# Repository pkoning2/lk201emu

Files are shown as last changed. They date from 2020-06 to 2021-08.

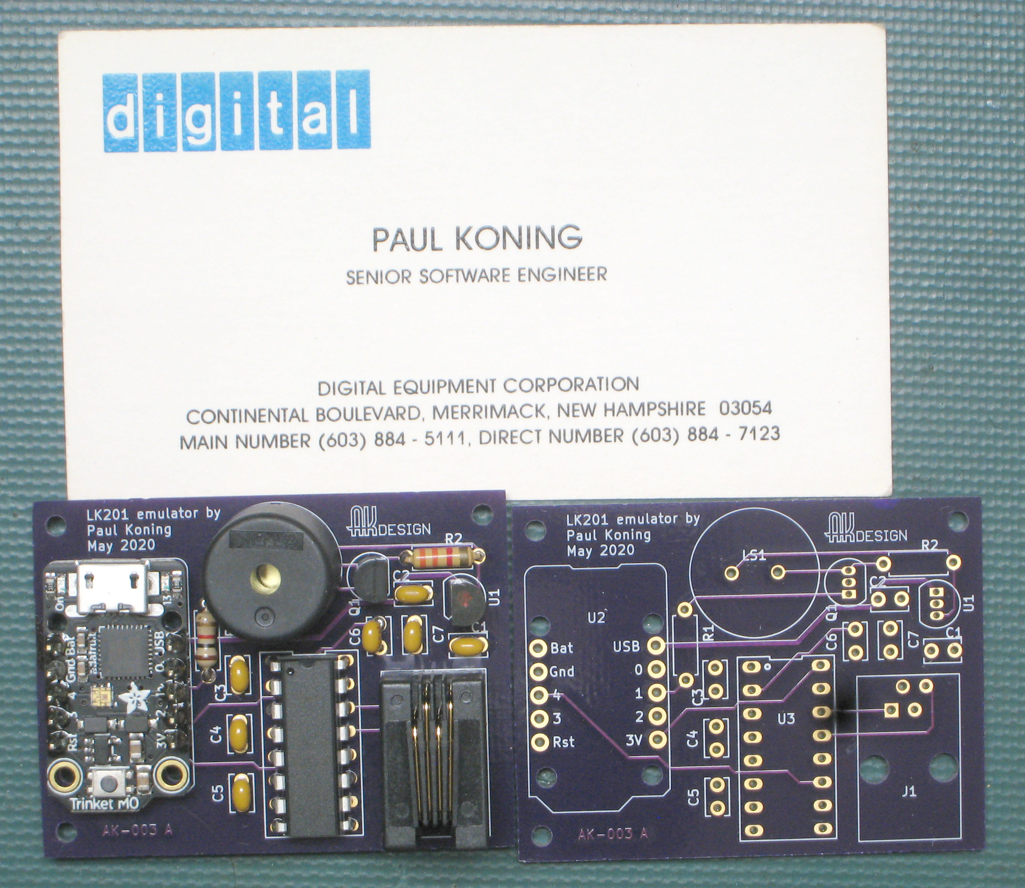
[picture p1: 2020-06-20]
doc/boards.jpg

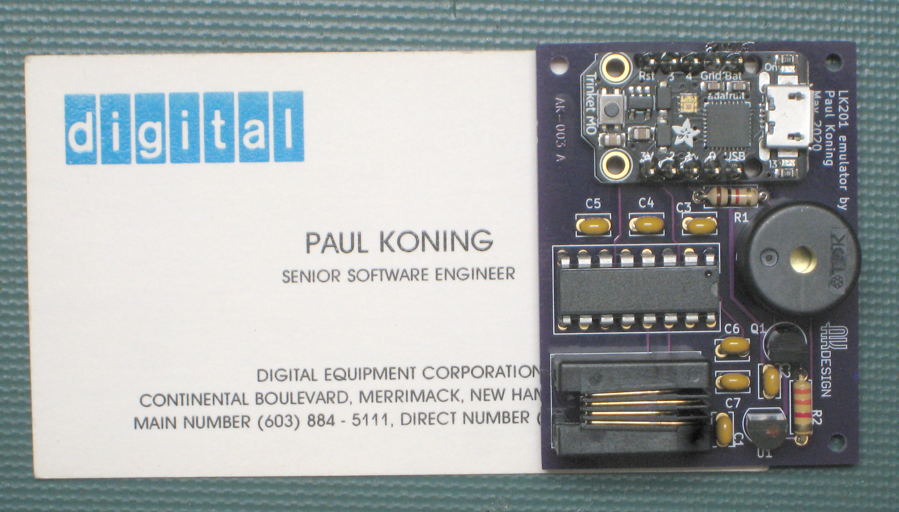
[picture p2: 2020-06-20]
doc/board.jpg

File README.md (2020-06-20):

# Digital Equipment LK201 keyboard emulator

This project allows a standard USB PC keyboard to be used as replacement for a DEC LK201 keyboard.  It consists of a small circuit built around an Adafruit Trinket M0 Arduino processor, and software for that to implement a USB host driver for the USB keyboard and the LK201 communication protocol. 

Subdirectory `lk201` is the Arduino software.  You can build it using the standard Arduino SDK, or use the prebuilt binary.

Subdirectory `kicad` is the circuit board design.  You can view it using the open source KiCAD package.

Subdirectory `doc` contains several documentation files in MD format.  File `emulator.md` describes the features of the emulator; `kicad` describes the board design and assembly information, and `software` describes the software and the load procedure.  There are also two JPG files that show the circuit board.

File `LICENSE` is the open source license under which this emulator is released.

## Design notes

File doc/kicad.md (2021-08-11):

# Digital Equipment LK201 keyboard emulators

The `kicad` subdirectory contains two subdirectories, `lk201` for the USB emulator and `lk201ps2` for the PS2 version.  In both you will find the design files for the emulator circuit board, which you can inspect or modify using the open source KiCAD package.

## Creating the circuit board

There are three ways to get a circuit board.
1. From the shared designs section of the OSHPark PCB fabricator website.  You will there both the [USB board](https://oshpark.com/shared_projects/zDjWDDDL "LK201 emulator") and the [PS2 board](https://oshpark.com/shared_projects/FJsOFwzi "LK201-PS2 emulator").
2. From any PCB fabricator that accepts KiCAD board files (such as OSHPark).
3. From any PCB fabricator that doesn't, by generating the standard *Gerber* files.

If you want to use a fabricator that needs Gerber files, open the `lk201.kicad_pcb` (USB) or `lk201ps2.kicad_pcb` (PS2) file using KiCAD (specifically the *Pcbnew* application) and use the File->Plot menu option to generate them.  You'll want to review the detailed instructions from the fabricator to confirm settings, file name rules, etc.

## Schematic

The board schematic is in `lk201.sch` (USB) or `lk201ps2.sch`.  You won't need this to create the board, but you can review this if you are interested, or if you want to modify the design.

## Assembly

The design is a simple circuit board with all through-hole components.  If you have experience building small electronic kits it should not create any problems.  If you do not, you may want to seek out some help since this is not a "Heathkit" style kit with detailed instructions or tutorials.

## USB board

### Parts list

Here are all the parts in the design, with schematic reference (also on the board silk screen labeling), value or device type, description, along with manufacturer name and Digikey part number.  The Digikey numbers are just by way of illustration.  Capacitors and resistors are generic, you can replace them by similar devices from other suppliers so long as they fit in the available space.  The capacitors  are small ceramic devices with 0.1 inch lead spacing; the resistors are standard 1/4 watt parts.  The transistor is a general purpose small NPN transistor, many other TO92 package transistors should work so long as the pinout matches.  Beware of the 2N2222, there are two variants with different pinouts!

If you don't want the key click and beep (bell) features, omit LS1, Q1, R1 and R2.
| Ref | Value | Description | Manufacturer | Digikey part # |
| --- | ----- | --- | --- | --- |
| C1 | 0.1uF | Unpolarized capacitor | Kemet | 399-14010-1-ND |
| C2 | 0.1uF | Unpolarized capacitor | Kemet | 399-14010-1-ND |
| C3 | 0.1uF | Unpolarized capacitor | Kemet | 399-14010-1-ND |
| C4 | 0.1uF | Unpolarized capacitor | Kemet | 399-14010-1-ND |
| C5 | 0.1uF | Unpolarized capacitor | Kemet | 399-14010-1-ND |
| C6 | 0.1uF | Unpolarized capacitor | Kemet | 399-14010-1-ND |
| C7 | 0.1uF | Unpolarized capacitor | Kemet | 399-14010-1-ND |
| J1 | RJ22 | RJ connector, 4P4C (4 positions 4 connected), RJ9/RJ10/RJ22 | Assmann WSW | AE10381-ND |
| LS1 | PS1420 | Crystal speaker/transducer | TDK Corporation | 445-2526-1-ND |
| Q1 | 2N3904 | 0.2A Ic, 40V Vce, Small Signal NPN Transistor, TO-92 | ON Semiconductor | 2N3904FS-ND |
| R1 | 1k | Resistor, 1/4 W | Stackpole | CF14JT1K00CT-ND |
| R2 | 3.3k | Resistor, 1/4 W | Stackpole | CF14JT3K30TR-ND |
| U1 | L78L05 | Positive 100mA 30V Linear Regulator, Fixed Output 5V, TO-92 | ST Microelectronics | 497-13127-1-ND |
| U2 | Trinket M0 | Adafruit Trinket M0 board (SAMD21) | Adafruit | 1528-2361-ND |
| U3 | ICL3232CPZ | Dual RS232 driver/receiver, 5V supply | Renesas | ICL3232CPZ-ND |

If you want to use Digikey as your supplier, the saved BOM is available [there](https://www.digikey.com/short/zrhrcz "Digikey BOM").

If you need alternate sources for various components, that should be no problem so long as the pinouts match.  For example, the MAX3232EPE transceiver has been reported as a valid alternative for U3.

### Assembly suggestions

I found that this order of installing the components works well:
1. U3 (16 pin DIP)
2. Resistors and capacitors
3. U1 (voltage regular) and Q1 (transistor)
4. LS1 (piezo beeper)
5. U2 (Trinket M0).  The board comes with a set of pins.  Cut off two 5-pin sections and solder these to the board, then slip the Trinket onto the pins and solder it.
6. J1 (RJ connector)

Note the correct orientation of U1, U2, U3, and Q1.

## PS2 board

### Parts list

Here are all the parts in the design, with schematic reference (also on the board silk screen labeling), value or device type, description, along with manufacturer name and Digikey part number.  The Digikey numbers are just by way of illustration.  Capacitors and resistor are generic, you can replace them by similar devices from other suppliers so long as they fit in the available space.  The capacitors  are small ceramic devices with 0.1 inch lead spacing; the resistors are standard 1/4 watt parts.  

If you don't want the key click and beep (bell) features, omit LS1 and R1.
| Ref | Value | Description | Manufacturer | Digikey part # |
| --- | ----- | --- | --- | --- |
| C1 | 0.1uF | Unpolarized capacitor | Kemet | 399-14010-1-ND |
| C2 | 0.01uF | Unpolarized capacitor | Kemet | 399-4150-1-ND |
| C3 | 0.1uF | Unpolarized capacitor | Kemet | 399-14010-1-ND |
| C4 | 0.1uF | Unpolarized capacitor | Kemet | 399-14010-1-ND |
| C5 | 0.1uF | Unpolarized capacitor | Kemet | 399-14010-1-ND |
| C6 | 0.1uF | Unpolarized capacitor | Kemet | 399-14010-1-ND |
| J1 | RJ22 | RJ connector, 4P4C (4 positions 4 connected), RJ9/RJ10/RJ22 | Assmann WSW | AE10381-ND |
| J2 | Mini-DIN-6 | 6-pin Mini-DIN connector | Adam Tech | 2057-MDJ-006-FS-ND |
| LS1 | PS1420 | Crystal speaker/transducer | TDK Corporation | 445-2526-1-ND |
| R1 | 3.3k | Resistor, 1/4 W | Stackpole | CF14JT3K30TR-ND |
| U1 | L78L05 | Positive 100mA 30V Linear Regulator, Fixed Output 5V, TO-92 | ST Microelectronics | 497-13127-1-ND |
| U1 | Itsy Bitsy (5V) | Adafruit Itsy Bitsy board, 5V version | Adafruit | 1528-2501-ND |
| U2 | ICL3232CPZ | Dual RS232 driver/receiver, 5V supply | Renesas | ICL3232CPZ-ND |

Warning: there are two versions of the Itsy Bitsy, as there are with many of the AVR based Arduino microcontrollers.  One has 3.3 volt I/O, the other has 5 volt I/O.  The PS2 design requires the 5 volt version.  Do not use the 3.3 volt version, it will be destroyed when you plug in the DEC side serial cable since that supplies 12 volts to the board and the 3.3 volt Arduino has a regulator that can only handle 6 volt max power input.  And even if the regulator could handle it, driving a PS2 keyboard with 3.3 volt logic levels will not work.

If you want to use Digikey as your supplier, the saved BOM is available [there](https://www.digikey.com/short/qbc941dj "Digikey PS2 BOM").

### Assembly suggestions

I found that this order of installing the components works well:
1. U2 (16 pin DIP)
2. Resistor and capacitors
4. LS1 (piezo beeper)
5. U1 (Arduino).  The board comes with a set of pins.  Cut off two 14-pin sections and a 5-pin section and solder these to the board, then slip the Itsy Bitsy onto the pins and solder it.
6. J1 (RJ) and J2 (mini-DIN) connectors.

Note the correct orientation of U1 and U2.

## Software load

After the board is built you will need to load the software.  See the software.md file for instructions.

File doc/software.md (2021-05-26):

# Digital Equipment LK201 keyboard emulators

The `lk201` subdirectory contains the software for the USB emulator circuit board, and the `lk201ps2` subdirectory contains the software for the PS2 emulator board.  These are two separate files, although the LK201 command parsing and serial link I/O code are the same in both files.  PC keyboard scan and decode are of course entirely different.  The audio output (beep and key click) are also different because of different hardware capabilities of the two Arduino devices used.

## Loading the software

### USB emulator board

An Arduino board such as the Adafruit Trinket M0 used in this project comes from the factory with a boot loader which is used to load the main program.  By default, the Trinket will connect as a device to the USB port of your computer.  But this emulator runs that same USB port in host (not device) mode, so after the initial programming it no longer talks directly to your PC or Mac by default.  The procedure given here also works fine for the initial load.

The solution is in the boot loader built into the Trinket:
1. Unplug the RJ22 serial cable (the connection to the DEC system).
2. Connect the Trinket to your computer.  If this is not the first time programming it, the Trinket will get power but will not make a connection because both sides are in USB host mode.
3. *Double click* the reset button.  The timing is slightly tricky; if done properly the small red LED next to the USB connector will blink (by slowly increasing and decreasing its intensity).  At this point, a `TRINKETBOOT` device will appear (USB attached FAT file system).
4. To use the prebuilt binary `lk201.uf2`, copy (drag and drop) that into the TRINKETBOOT device.  
5. Alternatively, use the Arduino SDK to compile and load the program source.

Either programming operation (3 or 4) will write the binary into the flash, then reset the Trinket (starting the software).  As a result the TRINKETBOOT device will suddenly disappear, which will probably result in a warning message from your computer's operating system about improper removal of the device. This is normal, the message can be ignored.

### PS2 emulator board

The PS2 emulator board is loaded through its micro-USB connector using the Arduino SDK.  

Unplug the RJ22 serial cable (the connection to the DEC system), then plug in a USB cable to your SDK machine.  Double click the reset button to enter the boot loader (the red LED on the Arduino board will blink), then use the SDK download operation.

## Dependencies

### USB emulator board

The `lk201.ino` source file is largely self contained.  To build it you will need the device libraries for the Adafruit Trinket M0 and the Adafruit ZeroTimer and DotStar libraries, all of which the SDK can download for you through the Library Manager.  You will also need the USB host library for SAMD based Arduino devices, available [on Github](https://github.com/gdsports/USB_Host_Library_SAMD "SAMD USB host library").

If you want to rebuild the `lk201.uf2` file, you will need the uf2conv.py utility available [on Github](https://github.com/microsoft.com "UF2 file format specification") in `utils/uf2conv.py`.  Proceed as follows:
1. Compile the program.
2. Use the `Export compiled binary` menu option to generate the `.bin` file.
3. Use `uv2conv.py` to convert that to a `.uf2` file.

### PS2 emulator board

The `lks201ps2.ino` source file is self-contained.  To build it you just need the device libraries for the Adafruit Trinket (classic AVR chip, not M0).

## Options

There is only one build option: change `#define DOIDENT 1` to `#define DOIDENT 0` to eliminate the identification message at device powerup.

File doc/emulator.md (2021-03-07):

# Digital Equipment LK201 keyboard emulators

The emulator allows a standard PC-style keyboard to be used as a replacement for a DEC LK201 keyboard.  This is useful if you don't have an LK201 keyboard, or if all the ones you have stopped working, as happened to me.

There are now two emulators: one for USB keyboards, and a different one for PS-2 (round connector) keyboards.  The circuit for the two is rather different, but the software functionality is the same for both.

The USB emulator circuit has two connectors: a modular jack which accepts the LK201 keyboard cable, and a USB connector.  The USB connector on the Trinket board is a micro-B connector; your keyboard presumably needs an A jack.  There are various ways to convert from one to the other; [Adafruit](https://www.adafruit.com/product/1099 "Micro B to A cable") sells one.

The PS2 emulator circuit has a modular jack for the LK201 keyboard cable and a standard PS2 mini-DIN connector for the keyboard.  If you have a very old PC keyboard with a standard size DIN connector (5 pins), you'll need an adapter for that; the board design I created does not accommodate a standard size connector.  Note that those old keyboards may have fewer keys, in which case you may want to adjust the key mapping in the software.  Also, some of them draw too much current for the regulator on the Arduino board.  If so, you will need to modify the circuit to add an external 12 to 5 volt regulator to feed the PS2 keyboard jack, rather than relying on the 5 volt out from the Arduino board.

## Keyboard mapping

For the most part, the keys on the PC keyboard correspond directly to the same keys on the LK201.  This applies to all the letters and digits as well as most punctuation.  Similarly, F1 through F12 are the same in both, as are the cursor keys and most of the numeric keypad keys.  Both shift keys are shift, but only the left control key is control.

Some other keys are different on the two keyboards.  Sometimes similar key labels exist but the positions are different; in that case I have chosen to map the keys by their positions.

| PC keyboard key | LK201 key |
| --- | --- |
| Left Windows | < > |
| Left Alt | Compose |
| Esc  | F11 |
| Insert | Find |
| Home | Insert Here |
| PgUp | Remove |
| Delete | Select |
| End | Prev Screen |
| PgDn | Next Screen  |
| PrtScr | F14 |
| Scroll Lock | Help (F15) |
| Pause | Do (F16) |
| Right Alt | F17 | 
| Right Windows | F18 |
| App Menu | F19 |
| Right Control | F20 |
| Num Lock | PF1 | 
| Num keypad / | PF2 |
| Num keypad * | PF3 |
| Num keypad + | Num keypad , |

Note that the PF4 and F13 keys are not available, I ran out of places to put them.

Also, on PS2 keyboards due to an oddity in the way the key is handled, the Pause key (used for the LK201 "Do" function) does not support LK201 up/down modes and will not auto-repeat.  The keyboard always pretends that this key is immediately released, so it is not possible to simulate the normal operation.

## Lights

Standard PC keyboards have only three LEDs, while the LK201 has four.  The mappings are:

| PC keyboard LED | LK201 keyboard LED |
| --- | --- |
| Scroll lock | Hold screen |
| Caps lock | Lock |
| Num lock | Compose |

The WAIT light is not on the keyboard but is provided by the LED on the center of the Arduino board.  On the USB version, that is a multi-color LED, set to green for the WAIT indicator.  On the PS2 board, this LED is red.

## Trinket middle LED color coding (USB keyboard emulator)

When operating, the emulator uses the middle LED for the LK201 WAIT light, in green.  Other colors are used during initialization, to reflect the phases of the USB discovery.
* Purple: settling.
* Blue: waiting for device.  This is the code you will see when no keyboard is plugged in.
* Yellow: attached, reset device.
* Orange: wait for device reset complete.
* Cyan (light blue): configuring device.  If the board stays in this state, the USB device is not compatible with this software.

When the USB initialization completes, there is a brief bright green flash.

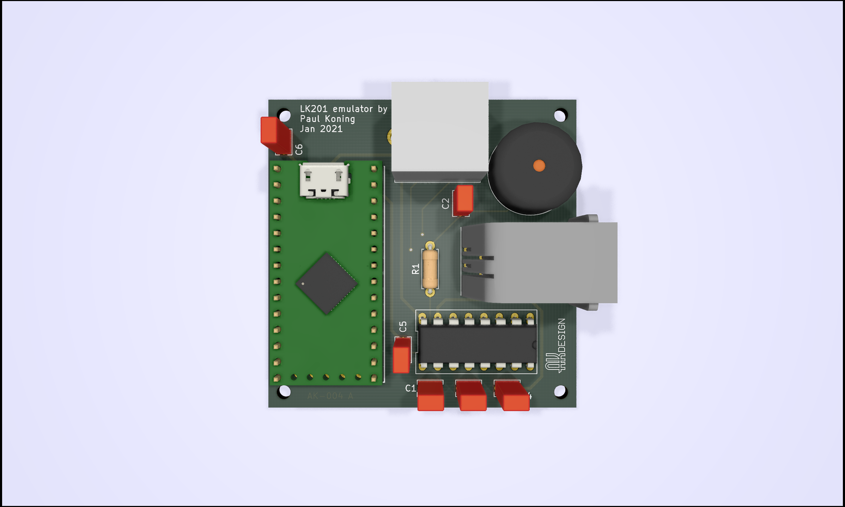
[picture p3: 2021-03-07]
kicad/lk201ps2/lk201ps2.png

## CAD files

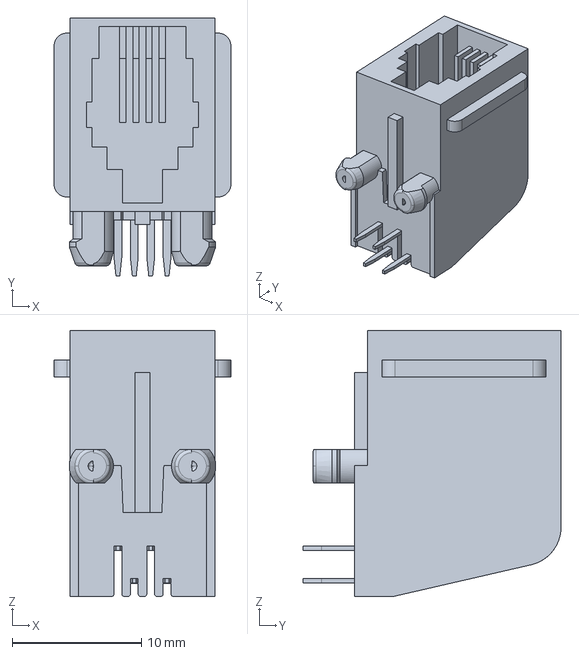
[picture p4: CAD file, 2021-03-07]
kicad/lk201_parts/modular_jack_a-20040.step
13.7 x 20.0 x 20.6 mm

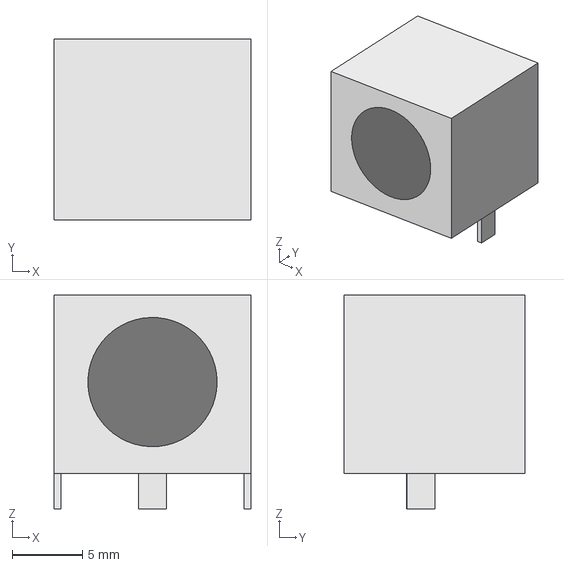
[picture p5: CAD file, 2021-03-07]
kicad/lk201_parts/MDJ-00x.step
14.0 x 12.9 x 15.2 mm

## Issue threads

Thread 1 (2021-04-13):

Some questions

toncho11, 2021-04-13:
Hi,

Great project! I have one vt220 without a keyboard and I would like to make one.

But you use a USB converter from the keyboard's USB type A to the MicroUSB of the Adafruit Trinket M0, right?

Do you have cards for sale?

pkoning2, 2021-04-14:
Thanks Toncho!

I assume by "converter" you mean some sort of active device.  No, it doesn't need that.  All that is needed is a cable that goes between the two connector types.  Adafruit has one, it is mentioned in the documentation (emulator.md), https://www.adafruit.com/product/1099 .
I don't have cards for sale.  My intent was to provide the design, both software and hardware.  You can buy the board (bare board) from OSH Park at the link given in kicad.md, or you can use the kicad design files to create a board file for some other fab shop if you prefer.  The parts are available from many suppliers; I included a BOM link at Digikey, but you can use others if you prefer.  The assembly instructions are included in the documentation as well.  It's a pretty simple item, just barely harder than "Heathkit".  In particular, no surface-mount parts.  A simple hobbyist-grade small soldering iron and some electronic-grade rosin-core solder is really all you need.

toncho11, 2021-04-30:
Hi again,

I got my card and I soldered the capacitors and resistors already. One thing is that there is not much space between the legs for the capacitors and especially for the transistor and the voltage regulator. One needs a very good soldering station with a thin head. I soldered two legs together at some point.

Question: is it possible to re-program the Adafruit Trinket while soldered? With the Arduino this is not the case because it does not accept a new program if the RX pin is connected to something. I will need to do adjustments in the code as my terminal is not a regular one. It has a modified ROM for my native language. So can you apply changes while it is already soldered? Maybe I should use a socket?

Thanks again for the project. I am advancing.

pkoning2, 2021-04-30:
Yes, the Trinket can be reprogrammed while soldered.  See the instructions in doc/software.md, section "Loading software".  This works because on the Trinket the programming operation does not use the UART, instead it uses the USB.

You mention that you have a "modified ROM".  Do you mean you have a terminal that uses a non-English LK201, for example the French (AZERTY) layout?  That does not make any difference.  The LK201 keycodes are for the key locations, so the keycode that is Q on the English model is used for A on the French one.  The handling of the different keyboard layouts is in the terminal microcode, not in the keyboard.  That does mean, of course, that you need a USB keyboard with the French layout if you have a terminal that wants a French LK201.  If you want to use an English layout USB keyboard for use with a French terminal, then yes, you'd have to change the translation table in my program so that -- for example -- the USB keystroke for the letter A is sent as the LK201 keycode for Q.

I have the Renesas RS232 part, which I get from Digikey -- a USA based distributor that has good prices, as does Mouser (also in the USA).  I don't know about similar companies in Europe, but I would expect they exist.  I would guess the CP would be comparable.  The main question is whether the pin assignment matches.  I would expect it does, normally the pins are standard and later versions of the same circuit use the same definitions.

toncho11, 2021-04-30:
No, it is not French, but Bulgarian. Actually I am not sure what to expect as I have not seen it in operation. It displays things in English, but with Cyrillic alphabet ...

Digikey ... can cost a lot for delivery (usually 20 euros) and then you might have import taxes of unknown value that you pay at delivery ... One guy says that for 52 euros of purchase he got 32 euros of additional taxes from UPS ...

pkoning2, 2021-04-30:
Toncho, I did not mean to suggest using Digikey if you're outside north America.  I understand the problem of shipping and taxes.  My idea was that I would expect companies similar to Digikey (electronic parts distributors) to exist in other parts of the world.  If there is one in the EU that would be a much better option for you.  Ebay is fine too, if the parts you get that way are real.
On the keyboard: if the terminal expects an LK201, the emulator should work.  A given key on your USB keyboard would have display the same way on that terminal as the corresponding key location does on a real LK201 keyboard.  If you don't know exactly what the layout should look like, the best answer is to use the existing software to start, and then test with that to see if any changes are needed.  The conversion from USB codes to LK201 codes comes from the usb_lk201 table in lk201.ino, you can change that to be any mapping you want, then rebuild and reload using the instructions in doc/software.md.

toncho11, 2021-04-30:
Here is a comparison with:

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

There is only 1 driver in the no Z version. Would this be a problem? Also size is a bit different.

pkoning2, 2021-04-30:
That is very strange.  I've searched for the ICL3232CP and as far as I can tell it is simply the same as the CPZ except that the CPZ is lead-free.  Certainly that's what the Renesas data sheets I have found tell me.
I can't see the information you posted.  Can you look at the data sheet referenced in the CP column and post it here?  I can look at it.  But it sounds like what you have there is not a real ICL3232CP.  I also don't know what it means to have an RS232 "transceiver".  It may be compatible, or not.
Your best solution is to search for another supplier who can sell you an actual ICL232CPZ.  Or any other 16-bit 2rx 2tx RS232 chip that has the same pinout.  It's a standard design, I'm sure there are other suppliers.  Just make sure that it handles 3.3 volt supply, 3.3 volt I/O, and has the correct pinout.

pkoning2, 2021-04-30:
Interesting.  I think Mouser is simply wrong, and the explanation is what I said: the CP is simply the older non-RoHS version of the CPZ.  So use either one.

toncho11, 2021-05-03:
MAX3232ECPE looks pin compatible. It is also 2rx 2tx. I can buy it from ebay/aliexpress without an expensive delivery.

pkoning2, 2021-05-03:
No, it's not.  That is an 18 pin device, not 16 pin.  You could certainly modify the design to use it, but the existing schematic and board won't work for that.

toncho11, 2021-05-03:
I do not see a pdip version with 18 pins in the specification. It says pdip 16?

https://eu.mouser.com/datasheet/2/256/MAX3222E-MAX3246E-349176.pdf

pkoning2, 2021-05-03:
You're right, my mistake.  I looked in the wrong spot.  I agree with you, that is a compatible part, it should work.

toncho11, 2021-05-20:
Hi,

For the PS1420 I already have a piezo beeper from another project:

Tension: 3,5 à 5,0 volts.
- Consommation: <25 ma.
- Fréquence: 2300 hz (+/- 500 hz).
- Puissance sonore: 85 dB minimum à 10cm.

It has + and - though. How should I put it?

pkoning2, 2021-05-20:
You're talking about the USB version, right?  Pin 1, on the left (near the Arduino board) is the + terminal.

toncho11, 2021-05-20:
Yes. USB. Thanks. It can be added on the board for the future versions :).

pkoning2, 2021-05-20:
You mean add a + symbol?  Good idea, will do.

toncho11, 2021-05-21:
Yes for the "+".

How did you solder the pins of the Adafruit chip? From both sides of your card?
These pins have a plastic part, did you remove it?

I ordered the last parts I need to complete your card. :)

pkoning2, 2021-05-21:
I soldered the pins only from the back of the board and the top of the Trinket.  Left the plastic in place.  I never solder things from both sides, because the solder reaches both sides anyway thanks to the plated through holes.

toncho11, 2021-07-15:
![Uploading IMG_20210715_202506.jpg…]()

This is the final product.

toncho11, 2021-07-15:
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

pkoning2, 2021-07-15:
Looks good!

Closed 2021-07-15.

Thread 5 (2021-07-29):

On using the adapter

toncho11, 2021-07-29:
Hi,

I managed to finally plug the adapter. In general it is working.

1) So the F3 key (on the USB keyboard) switches between menu and writing modes? Right?
2) Can you type (do letters show) on the VT220 terminal without attaching it to a computer through serial?

I use the right "ENTER" for selecting options in the menu.

pkoning2, 2021-07-29:
Yes, F3 is the "Setup" function key on VT2xx and later terminals.  (Not on the Pro, though, it has a different function key layout.)
I don't have a VT220, so I have to look in a manual to remind myself what it does.  The way I normally navigate the menu is using the cursor  keys, then Enter to do the selected action.
One of the options on the first setup screen is "On-line" which if you select and Enter should change to "Local".  That makes keyboard data go to the display directly, without any communication to any host.
The red light on the Arduino is the "Wait" LED (the fourth LED on the LK201).  I did it that way because I want all four to be visible, the other three are handled using the three PS keyboard LEDs.  See the documentation, it's mentioned in there.

toncho11, 2021-08-01:
Thanks!!!

The terminal though is only in cyrillic letters using English words in whatever language you choose. I guess they adapted the ROM, so that one can type in cyrillic, but in the end I do not see how to switch to English. It is because cyrillic was not built in, so they had to make un eagly hack. I think the only solution is an original ROM.

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

pkoning2, 2021-08-01:
Yes, looks like they replaced lower case letters by Cyrillic capital letters.  The original ROM would be the best solution.  Or use only upper case...

toncho11, 2021-08-01:
Nice observation! It does work with capital letters in English.
I still need both if I want to connect to a Linux terminal.
Some strategy can be developed!

I can add a code after your code in the adafruit controller:
- each capital letter is converted to lower initially
- when F6 (for example) is pressed then it goes upper case

toncho11, 2021-08-02:
Actually I need another micro controller on the serial port output in order to do that, The display will always stay in English capital letters even if I manage to send both lower and capital letters to the connected computer,

toncho11, 2021-08-11:
You can update that:

Max3232EPE driver/receiver is also compatible as U3.

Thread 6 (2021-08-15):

Keyboard blinking constantly, very intermittent keypresses going through

abzman, 2021-08-15:
OK, this has been bugging me for a while and I think I've finally fixed it but I want to know how this ever worked for anyone else.  The lines 938-940 in lk201.ino seem to mean that every time the keyboard is connected, the software disconnects it.  I commented out those three lines and now it works perfectly.  What I want to know is why were those lines in there at all? did it work as is for anyone else? should I issue a pull request that deletes those three lines?

abzman, 2021-08-15:
I take it back, it doesn't work perfectly for me now, it boots up and the usb state goes to green, then off just before it throws a keyboard error, but after that any character I type makes it green again and seems to work perfectly

pkoning2, 2021-08-18:
Unfortunately it's hard to do good error handling given that there is no real way to send error reports.  At one point I had it send various distinct error codes as different morse code letters.
The purpose of line 938 is to send the standard LK201 power-up notification to the host or terminal.  That tells it there is a keyboard, and if the controlling device wants to set any non-standard keyboard settings it would generally do so in response to that notification.  For example, RSTS would change the edit keys to be autorepeat, not up/down as is the surprising default, and it would turn off keyclick so it can generate clicks in the driver to acknowledge those keys for which it wants the click.
Do you have the powerup beeping enabled (the little morse code sequence)?  If there's an error that crashes the controller it would resend that sequence.  If you're just seeing various light colors and blinking, that means the USB state machine is recycling through its state.  I could imagine that being a broken keyboard, or a bad USB cable.  If you can swap keyboards or cables or the cable adapter, that's worth a try.
It's been very reliable for me (though right now I'm using the PS2 version instead) and I've had one other report of successful operation (toncho11, who posted various comments here in weeks past).

abzman, 2021-08-18:
I've been working on other projects so I may not get to debugging this for a little while, I have two brand new keyboards to use with this but I have three others to try as well.  I know the keyboards work, but I'm not hearing any beeping.  My next test was to make sure my beeper circuit works.  I'll let you know how it goes, I may try to bodge on a software serial port for debug messages

pkoning2, 2021-11-05:
Any news?  Did you get it to work or are you still seeing problems?

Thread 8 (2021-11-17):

No reason the PS/2 emulator couldn't be implemented on an Arduino Pro Micro?

ej0rge, 2021-11-17:
Hey, i am excited about this project. I have a VT220 and a working LK201 (and VT1200 and LK401) but i loathe the key feel of these old membrane keyboards. I've got boards inbound from jlcpcb.

I've got no heartburn about ordering an Itsy Bitsy 5v from adafruit, but i have a thing for building things Small, no real fear of light duty hot air smt work, and half a dozen Arduino Pro Micro 5v clone boards in a drawer.

The Itsy Bitsy is cheaper than a Genuino Pro Micro, but 3x the cost of a chinese clone Pro Micro.

I sort of know my way around kicad and while I'm a terrible coder i can manage to make small changes without getting completely lost. It looks like at worst i might have to use different pins for the PS/2 interface if i compiled for the APM.

After looking through the schematic I am pretty sure i could lay out a board with an smt max232 equivalent and smt capacitors and resistor on a board no wider than the APM and fit a buzzer under there too, with the mini-din 6 on one end and rj22 (or just a JST-XH for a custom cable) on the other. And design a very small 3d printed enclosure, maybe with a cable clamp for telephone station cable with an RJ22 plug crimped on the end. I have a crimper and ends, pretty sure.

I would consider this a fun project.

Am i missing anything?

pkoning2, 2021-11-17:
Hi, thanks for the feedback.

The only real requirement is that you have an Arduino, and it should have 5V I/O, with enough pins to drive the signals used in the design.  I did my original debugging with a Metro prototyping board.  If you don't use an Itsy Bitsy then you probably need to adjust the board.   If the pinouts differ then that may need to change as well, and if that means different pin numbers the "pin assignment" defines at the top of the source file would need adjustment.

If necessary you can leave out the buzzer, though of course that means no key click and no "bell".  If your board doesn't have a built-in LED, then either you can omit the WAIT LED, or wire up an LED to some available pin and change the WAITLED define to match.

The changes you proposed all sound fine.  I'd like to see your finished work, it sounds nice.

ej0rge, 2021-11-18:
Yes the pins of the two modules are substantially different, and the PS/2 port will have to be assigned to different pins when the firmware is built.

I think I'll keep the buzzer but might use a different part.  I haven't dug into the code but it looks like you are using a pwm pin to drive it through the unused output pin on the 232 driver. Clever. That same pin is still broken out on the arduino pro mini.

pkoning2, 2021-11-18:
Yes, the idea of driving a buzzer through an RS-232 driver was lifted from another LK201 adapter design.  The PWM is to get the variable loudness.  And the RC filter actually makes that work; unfiltered the different width pulses sound different in character but not really in loudness.

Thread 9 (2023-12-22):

Thanks and suggestion for function keys > 12

snhirsch, 2023-12-22:
First of all, thanks for your efforts in developing these devices.  I built a USB converter and everything went quite well.

I do have a suggestion / wish-list item:  Why not map Shift + Fn to F(n+10)?  That's somewhat common in both the Windows and Linux ecosystems.  Rather than move to the bottom right for, e.g. F17 one could just do Shift+F7.  Is there a technical reason that would prevent this from working?

pkoning2, 2023-12-22:
That would be somewhat tricky.  Keep in mind that this is basically a scan code translator.  So when you press F7 it sends the keycode for that; when you press a shift key it sends the keycode for shift.  The converter doesn't care about the shift state when it generates the keycodes; the host driver is responsible for that aspect.
While it may be that shifted function keys have no standard meaning in typical DEC products, there certainly isn't anything that prevents that from being done, at least not in systems where that processing is in software (like the DEC Pro).

snhirsch, 2023-12-22:
Ah - ok.  I definitely see your point.  Didn't realize the converter held no state!  But as you say that is definitely the safest and most compatible approach.

pkoning2, 2023-12-23:
It does have some state, because it has to send "all up" when the last of the up/down keys is released, rather than the keycode for that key.  But other than that the coding of the keys does not depend on shift or other modifier state.

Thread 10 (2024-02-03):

Help needed

Kisko93005, 2024-02-03:
Hello,
Recently, I've took out an old Rainbow 100 computer with an VR201 and lk201 keyboard from my basement. After trying to boot it up i was given an keyboard error 13. After I disconnected membrane ribbons from keyboard's electronics the computer booted normally, which most likely means shorted membrane, which is apparently impossible to repair.

Trying to find solution to my problem i have found this project. Because Adafruit Trinket M0 is almost imposible to get in my country without paying huge shipping costs for an international courier delivery I tried to make PS/2 version of your project. I don't have an Itsy Bitsy but i have a arduino micro which uses the same exact processor. After wiring it to PS/2 keyboard and the Rainbow through ADM232 chip(I connected everything according to the schematic except i changed PS/2 keyboard pins (physically and in the code) from 11 and 12 to 5 and 6 because there's no pin 11 on my arduino micro) I powered it up but it gives me keyboard error 13. I don't know what to do anymore.

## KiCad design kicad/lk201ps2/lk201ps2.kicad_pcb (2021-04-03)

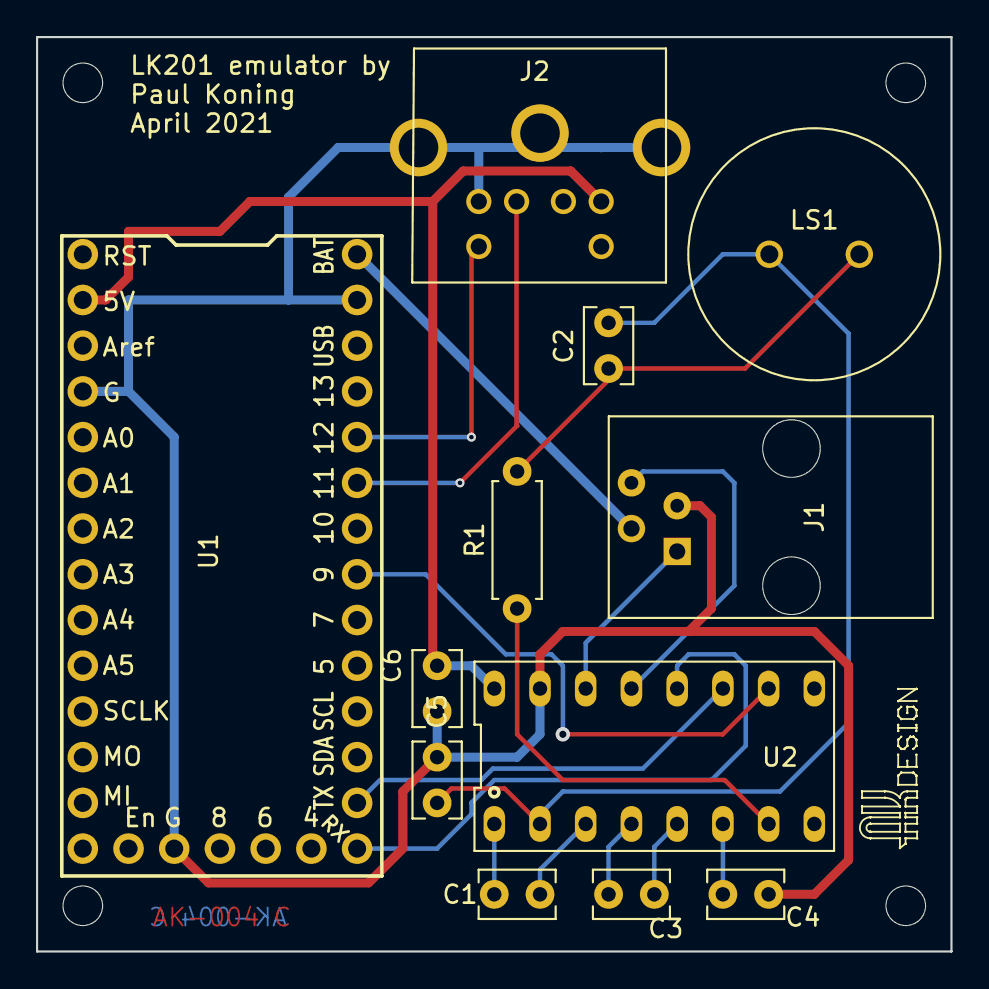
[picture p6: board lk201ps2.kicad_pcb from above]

Board: 2 copper layers, 50.8 x 50.8 mm, 12 parts (0 on the bottom side), 18 nets.

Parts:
C1, C3, C4, C5, C6: 0.1uF; C_Rect_L4.0mm_W2.5mm_P2.54mm
C2: 0.01uF; C_Rect_L4.0mm_W2.5mm_P2.54mm
J1: RJ22
J2: Mini-DIN-6; MDJ-006
LS1: PS1420; PS1420_buzzer
R1: 3.3k; R_Axial_DIN0207_L6.3mm_D2.5mm_P7.62mm_Horizontal
U1: Itsy_Bitsy_5V; Itsy
U2: ICL3232CPZ; DIP-16_296_ELL

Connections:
/V5: C6.1, J2.4, U1.2, U2.16
/V12: J1.2, U1.33
/VS+: C2.2, C5.2, LS1.2, U2.2
GND: C4.1, C5.1, C6.2, J1.3, J2.3, J2.SH, U1.4, U1.16, U1.32, U2.15
unnamed: C1.1, U2.1
unnamed: C1.2, U2.3
unnamed: C2.1, LS1.1, R1.2
unnamed: C3.1, U2.4
unnamed: C3.2, U2.5
unnamed: C4.2, U2.6
unnamed: J1.1, U2.14
unnamed: J1.4, U2.13
unnamed: J2.1, U1.28
unnamed: J2.5, U1.29
unnamed: R1.1, U2.7
unnamed: U1.20, U2.12
unnamed: U1.21, U2.11
unnamed: U1.26, U2.10

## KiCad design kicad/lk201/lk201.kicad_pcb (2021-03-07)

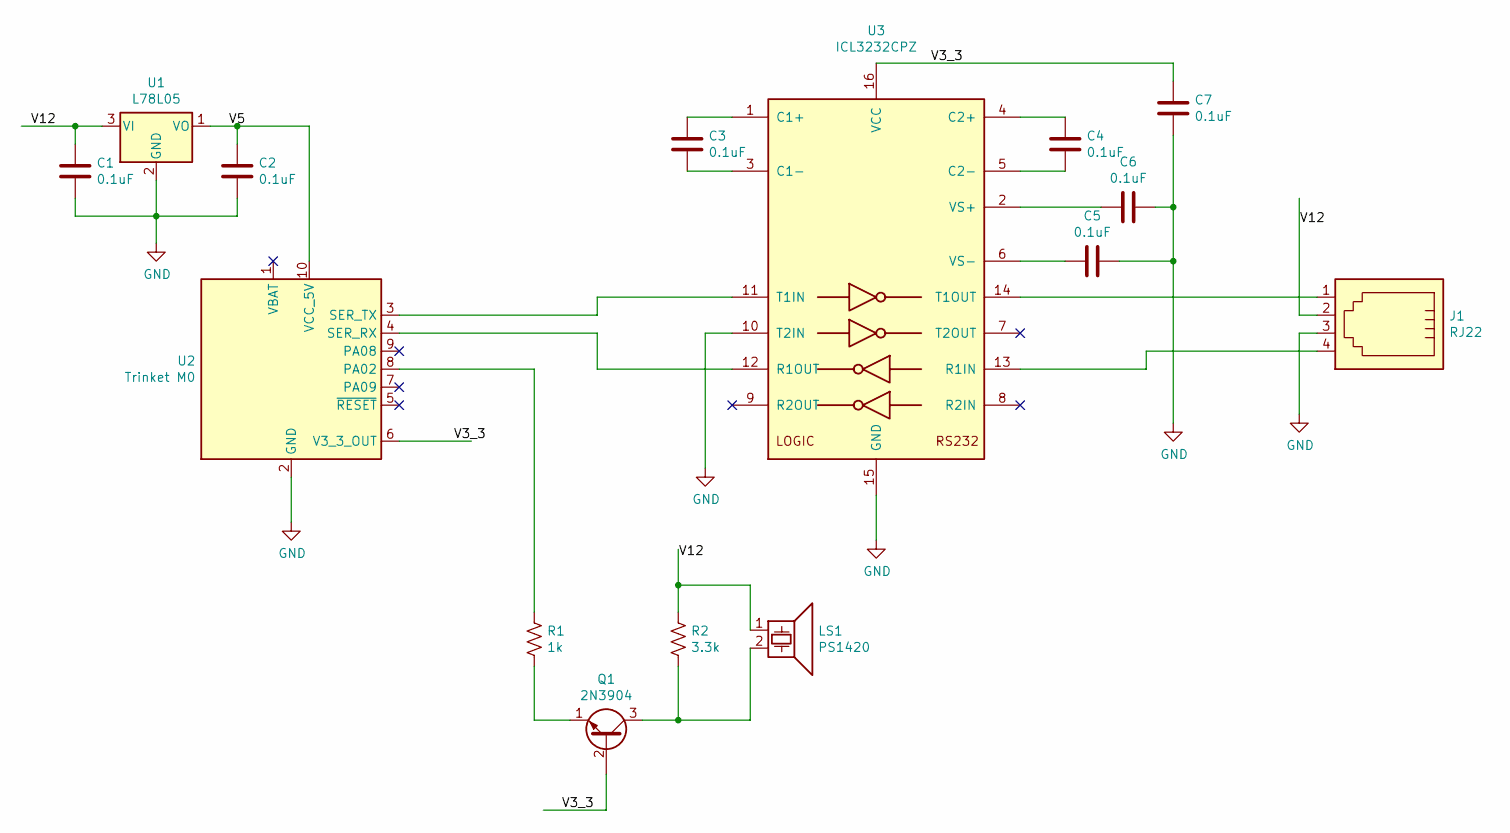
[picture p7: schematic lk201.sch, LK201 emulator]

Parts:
C1, C2, C3, C4, C5, C6, C7: 0.1uF; C_Rect_L4.0mm_W2.5mm_P2.54mm
J1: RJ22; Mfg part A-2004-3-4-LP-N-R; Digikey  AE10381-ND
LS1: PS1420; PS1420_buzzer
Q1: 2N3904; TO-92_Inline_Narrow_Oval
R1: 1k; R_Axial_DIN0207_L6.3mm_D2.5mm_P7.62mm_Horizontal; Mfg part CF14JT1K00; Digikey CF14JT1K00CT-ND
R2: 3.3k; R_Axial_DIN0207_L6.3mm_D2.5mm_P7.62mm_Horizontal; Mfg part CF14JT3K30; Digikey CF14JT3K30TR-ND
U1: L78L05; TO-92_Inline_Narrow_Oval
U2: Trinket M0; Trinket_M0; Mfg part 3500; Digikey 1528-2361-ND
U3: ICL3232CPZ; DIP-16_296_ELL; Mfg part ICL3232CPZ; Digikey ICL3232CPZ-ND 

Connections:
/V3_3: C7.1, Q1.2 (B), U2.6 (V3_3_OUT), U3.16 (VCC)
/V5: C2.1, U1.1 (VO), U2.10 (VCC_5V)
/V12: C1.1, J1.2, LS1.1, R2.1, U1.3 (VI)
GND: C1.2, C2.2, C5.1, C6.1, C7.2, J1.3, U1.2 (GND), U2.2 (GND), U3.10 (T2IN), U3.15 (GND)
unnamed: C3.1, U3.1 (C1+)
unnamed: C3.2, U3.3 (C1-)
unnamed: C4.1, U3.4 (C2+)
unnamed: C4.2, U3.5 (C2-)
unnamed: C5.2, U3.6 (VS-)
unnamed: C6.2, U3.2 (VS+)
unnamed: J1.1, U3.14 (T1OUT)
unnamed: J1.4, U3.13 (R1IN)
unnamed: LS1.2, Q1.3 (C), R2.2
unnamed: Q1.1 (E), R1.2
unnamed: R1.1, U2.8 (PA02)
unnamed: U2.3 (SER_TX), U3.11 (T1IN)
unnamed: U2.4 (SER_RX), U3.12 (R1OUT)

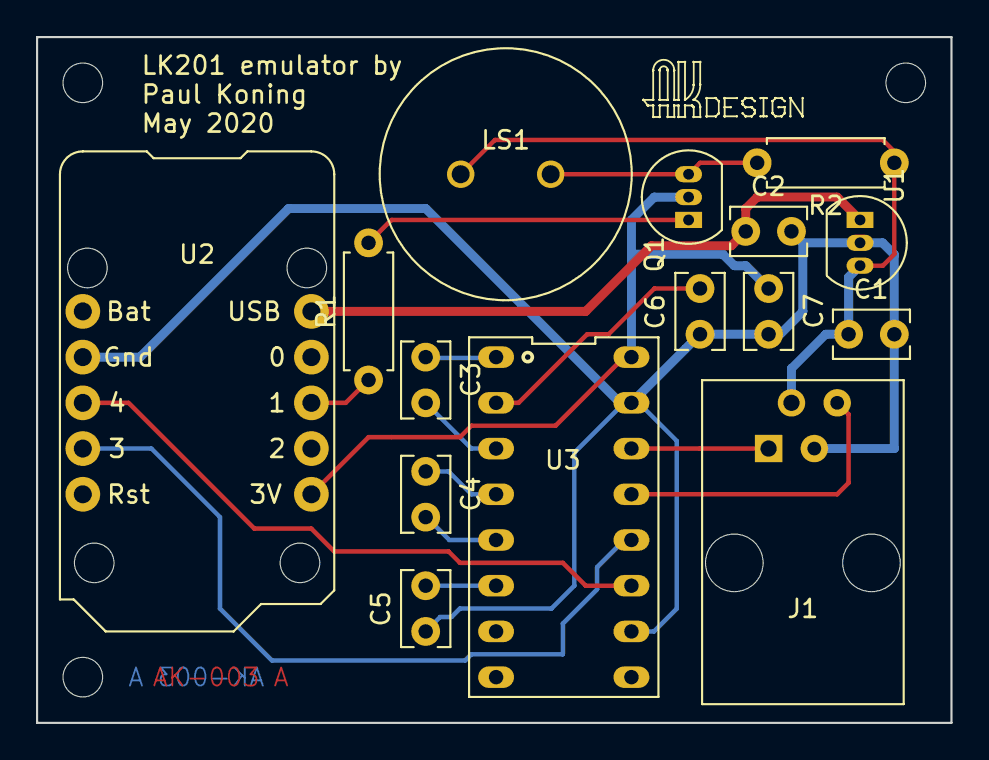
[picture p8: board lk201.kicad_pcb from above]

Board: 2 copper layers, 50.8 x 38.1 mm, 15 parts (0 on the bottom side), 17 nets.

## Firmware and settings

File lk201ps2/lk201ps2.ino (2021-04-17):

/*
 LK-201 emulator

 Interfaces between a DEC terminal or workstation that expects an
 LK201-AA keyboard and a standard PS2 connector PC keyboard.

 Copyright (c) 2020-2021, Paul Koning

 Please read file LICENSE for the license that applies to this project.
*/

#define DOIDENT 1   // Set to 0 to suppress power up ident

/*
 Parts of this code were taken from various sample files:

 Polled PS-2 keyboard controller copyright 2009 by Bill Westfield.
 */

#include <Arduino.h>

#include "wiring_private.h"
#include "pins_arduino.h"

// Pin assignment

#define APIN 9              // PWM output, 2 kHz.
#define PS2CLK 12
#define PS2DAT 11
#define WAITLED LED_BUILTIN // pin for Wait LED


// PC 105-key keyboard to LK201 mapping.
//
// Entries in the main lookup table are keyed by the scan code.  The
// value is the LK201 keycode.  Entries in the "divs" table are keyed
// by LK201 keycode, and give the "keyboard division" number which
// selects the mode (up/down, autorepeat, down only) and, if
// applicable, autorepeat parameter buffer.
//
// For the most part these mappings are obvious.  The 6 editing keys
// (above the cursor keys) are mapped according to their location, not
// their labels, so "home" is coded as LK201 "insert here" (rather than
// using the "insert" key for this code).
//
// Similarly, num lock, scroll lock and pause become F14, F15 (Help)
// and F16 (Do).  And the numeric keypad mappings are by layout.  Note
// that there is no PF4 because the PC keypad has one key less than the
// LK201, so the - key is used for - (Cut) instead of PF4 as its
// placement might suggest.
//
// The left Windows key is the < > key.
//
// For convenience, Esc is mapped to F11 which is its conventional
// interpretation.  Both shifts are shift, but the right
// Alt/Win/App/Ctrl keys are F17 to F20 instead.

const uint8_t divs[] =
{
    10, 10, 10, 10, 10, 0, 0, 0, 0, 0, 0, 0, 0, 0,
    11, 11, 11, 11, 11, 0, 0, 0, 0, 0, 0, 0, 0,
    12, 12, 12, 12, 0, 0, 0, 0, 0, 0, 0, 13, 13, 0, 0,
    14, 14, 14, 14, 0, 0, 0, 0, 0, 0, 9, 9, 9, 9, 9, 9,
    0, 0, 2, 0, 2, 2, 2, 2, 2, 2, 2, 2, 2, 2, 2, 2, 2, 2, 2, 2,
    0, 0, 0, 7, 7, 8, 8, 0, 0, 0, 6, 6, 5, 5, 0, 0, 0, 0,
    0, 0, 0, 0, 0, 0, 3, 4, 4, 1, 1, 1, 1, 1, 0, 1, 1, 1, 1, 1,
    0, 1, 1, 1, 1, 0, 1, 1, 1, 1, 1, 0, 1, 1, 1, 1, 0,
    1, 1, 1, 1, 0, 1, 1, 1, 1, 0, 1, 1, 1, 1, 0, 1, 1, 1, 1, 0,
    1, 1, 0, 1, 1, 0, 1, 1, 1, 0, 1, 1, 1
};
// First LK201 code in divs is 86
#define DIVBASE 86

// LK201 division mode codes
#define D 0         // Down only
#define A 1         // Autorepeat
#define U 3         // Up/down

// Default mode settings for the divisions.  Note that divisions are
// numbered starting at 1.
// Defaults are: main, keypad, delete, cursor - autorepeat; return,
// tab, lock, compose: down only; shift, control, editing: down/up.
// Documentation doesn't say what we do for function keys: make those
// down only.
// Division 0 doesn't exist, we use it internally for special keys
// like ALL UP.  Set it to up/down so those are always sent.
const uint8_t defmodes[] =
{ U, A, A, A, D, D, U, A, A, U, D, D, D, D, D };

// Active modes, loaded from defmode at reset but can be modified by
// the host.
uint8_t modes[sizeof (defmodes)];

// Auto-repeat buffers
struct arparams
{
    int timeout;      // Delay before first repeat in ms
    int interval;     // Delay between subsequent repeats in ms
};

#define WPM2MS(x)  (1200 / (x))
#define RATE2DELAY(x) (1000 / (x))
#define ARBUF(tmo,rate) { tmo, RATE2DELAY (rate) }

const arparams defarbufs[4] =
{
    ARBUF (500, 30),
    ARBUF (300, 30),
    ARBUF (500, 40),
    ARBUF (300, 40)
};

// These are the active params, loaded at reset but changeable.
arparams arbufs[4];

// Auto-repeat buffer assignments for divisions.  Documentation
// doesn't state what the default assignment is for divisions that
// don't default to autorepeat; use zero for those.
const uint8_t defar[] =
{ 0, 0, 0, 1, 0, 0, 0, 1, 1, 0, 0, 0, 0, 0, 0 };

// Active auto-repeat buffer assignments, loaded from defar at reset
// but can be modified by the host.
uint8_t ar[sizeof (defar)];

// Current auto-repeat values
unsigned long int arTime;
const arparams *arBuf;
int nextArKey;

// Ident stuff
#define IDUNIT WPM2MS (30)   // 30 wpm
#define T 1
#define H (T * 3)
#define S (-T)
#define LS (-H)

const int8_t errB[] =
{ LS, H, S, T, S, T, S, T, LS, 0 };

const int8_t errP[] =
{ LS, T, S, H, S, H, S, T, LS, 0 };

const int8_t errX[] =
{ LS, T, S, T, S, T, S, T, S, T, S, T, S, T, S, T, LS, 0 };

#if DOIDENT
// "de ni1d"
const int8_t ident[] =
{
    H, S, T, S, T, LS, T, LS, LS, S,
    H, S, T, LS, T, S, T, LS,
    T, S, H, S, H, S, H, S, H, LS,
    H, S, T, S, T, 0 
};
#endif

// Key click and bell parameters
bool clickOff = false;
bool ctrlClick = false;
int clickVol;
bool bellOff = false;
int bellVol;
#define DEFVOL 2    // that means 3rd highest -- the coding is inverted.
#define IDVOL  4    // medium for ID string

// Max would be half of the PWM top value, i.e., 255 (square wave) but
// that produces a distinctly different sounding tone than the
// narrower pulses do.  So set full scale a bit lower to avoid that.
#define FS 200

#define P 0.707
#define E(i, b, pp) ((i & (1 << b)) ? (pp): 1)

// Volume table (analog output value for a given volume).  Note that 0
// is highest.  We scale exponentially since audio perception is
// logarithmic.  The exponent (P) is determined experimentally, by
// looking for something that sounds right.  Sqrt(0.5) seems about
// right.
#define VOL(i) (FS * E(i, 2, P*P*P*P) * E(i, 1, P*P) * E(i, 0, P))
const int vol[8] =
{
  VOL (0), VOL (1), VOL (2), VOL (3),
  VOL (4), VOL (5), VOL (6), VOL (7)
};

// Audio generation control
#define CLICKTIME 5         // 5 ms tone produces a good click
#define BELLTIME  125       // 125 ms tone

void doClick (void)
{
    if (!clickOff)
    {
        analogWrite (APIN, vol[clickVol]);
        delay (CLICKTIME);
        analogWrite (APIN, 0);
    }
}

void doBell (void)
{
    if (!bellOff)
    {
        analogWrite (APIN, vol[bellVol]);
        delay (BELLTIME);
        analogWrite (APIN, 0);
    }
}

// Use the pin 0/1 serial port
#define Serial Serial1

/*
 * ps2kpolled.c
 *
 * Copyright 2009 by Bill Westfield
 *
 * Polled driver for PS2-style keyboards.
 * See http://www.beyondlogic.org/keyboard/keybrd.htm
 */

// Max time in microseconds to wait for the keyboard to say something.
#define MAXPOLL 1000UL

unsigned char ps2k_clk, ps2k_dat;

#define WAITLOW(pin) while (digitalRead(pin) != LOW) ;
#define WAITHIGH(pin) while (digitalRead(pin) != HIGH) ;

/*
 * ps2k_init
 * initialize our interface to a PS2 keyboard.
 *
 * The normal inactive state of the keyboard interface is (a) CLK is
 * output and driven LOW to block keyboard transmissions, (b) DATA is
 * open-collector input and pulled up.
 *
 * Keyboard action functions that need to change any of this are
 * expected to return things to their normal state on exit.
 */
void ps2k_init (unsigned char clock, unsigned char data)
{
    ps2k_clk = clock;
    ps2k_dat = data;
    pinMode(ps2k_clk, OUTPUT);
    digitalWrite(ps2k_clk, LOW);    /* Claim the clock */
    pinMode(ps2k_dat, INPUT_PULLUP);
    digitalWrite(ps2k_dat, HIGH);   /* Enable pullup */
}

/*
 * _ps2k_getcode
 * Read a single keycode from a PS2 keyboard.  This may be a leadin
 * to a multi-symbol key, or an acknowledgement, or a key-release
 * event; we don't care at all.
 *
 * This is only an internal subroutine; note that it does NOT release
 * the clock signal to enable the keyboard to send any data.
 *
 * Interrupts should be disabled on entry; on exit they are still
 * disabled.
 */
static unsigned char _ps2k_getcode(void)
{
    unsigned char keycode, i, parity;
    unsigned long start = micros ();
    unsigned char pin;
    
    // Wait for a Start bit, but not longer than a millisecond.  We do
    // this to avoid getting stuck in this function if the keyboard
    // has nothing to say.
    while (digitalRead (ps2k_clk) == HIGH)
    {
        if (micros () - start > MAXPOLL)
        {
            // time is up, return "no data"
            return 0;
        }
    }
    WAITHIGH(ps2k_clk);         /*  Discard start bit */

    keycode = parity = 0;
    for (i=0; i<10; i++)        /* Read 8 data bits, parity, stop */
    {
        WAITLOW(ps2k_clk);      /*   On each falling edge of clock */
        pin = digitalRead (ps2k_dat);
        if (i < 8)
        {
            keycode >>= 1;      /* LSB is sent first, shift in bits */
            if (pin == HIGH)
            {                   /*   from the MSB of the result */
                keycode |= 0x80;
            }
        }
        if (i < 9 && pin == HIGH)
        {
            parity ^= 1;        /* Accumulate parity */
        }
        WAITHIGH(ps2k_clk);     /* prepare for next clock transition */
    }
    if (parity != 1)
    {
        // Parity error.  Report that to caller with a return value
        // that isn't used as either a scan code or a status code.
        keycode = 0xfb;
    }
    return(keycode);
}

/*
 * ps2k_getkey
 * Leaves the keyboard with our host driving the clock signal low, which
 * forces the keyboard to buffer (and not send) additional data.
 */
int ps2k_getkey(void)
{
    int result;

    result = 0;

    noInterrupts ();
    pinMode(ps2k_clk, INPUT_PULLUP);
    digitalWrite(ps2k_clk, HIGH);  /* release ownership; let keybd send */

    result = _ps2k_getcode();      /* Get one byte of keycode */
    pinMode(ps2k_clk, OUTPUT);
    digitalWrite(ps2k_clk, LOW);   /* (stops keyboard from additional sends) */
    interrupts ();

    // To make sure the keyboard sees the clock low, hold it for 200
    // microseconds.  That ensures any transfer started right at the
    // instance we gave up waiting is aborted rather than continuing
    // if another poll happens immediately after exit.
    delayMicroseconds (200);

    return result;
}

/*
 * ps2k_sendbyte
 * Send a byte from the host to the keyboard.
 * This is ... complicated, because even though the host is sending the
 * data, the keyboard does the clocking.  I had all sorts of troubles
 * with terminating the write, apparently solved by the insertion of
 * the "delayMicroseconds()" call after the parity bit.
 *
 * Note that this routine does not process any response codes that the
 * keyboard might send.  They'll show up to ps2k_getkey and will need to
 * be ignorned (or not, as the case may be.)
 */
void ps2k_sendbyte(unsigned char code)
{
    unsigned char parity = 0;       /* Get first byte */
    unsigned char i;

    pinMode(ps2k_dat, OUTPUT);
    digitalWrite(ps2k_dat, LOW);      /* Say we want to send data */

    pinMode(ps2k_clk, INPUT_PULLUP);
    digitalWrite(ps2k_clk, HIGH);

    WAITLOW(ps2k_clk);              /* Send Start bit */

    for (i = 0; i < 8; i++)         /* Send 8 data bits, LSB first */
    {
        if (code & 0x1)
        {
            digitalWrite(ps2k_dat, HIGH);
            parity++;               /* Count one bits to calculate parity */
        }
        else
        {
            digitalWrite(ps2k_dat, LOW);
        }
        WAITHIGH(ps2k_clk);
        WAITLOW(ps2k_clk);
        code >>= 1;                 /* Shift to get next bit ready. */
    }

    if ((parity & 0x1))             /* Send proper parity bit */
    {
        digitalWrite(ps2k_dat, LOW);
    }
    else
    {
        digitalWrite(ps2k_dat, HIGH);
    }
    WAITHIGH(ps2k_clk);
    WAITLOW(ps2k_clk);

    pinMode(ps2k_dat, INPUT_PULLUP); /* Switch back to input / OC mode */
    digitalWrite(ps2k_dat, HIGH);   /* This sends the STOP bit */

    WAITHIGH(ps2k_clk);             /* Wait for end of stop bit time */
    WAITLOW(ps2k_clk);              /* Wait for ACK from keyboard */
    /* TBD: should we look at the ACK signal? */
    WAITHIGH(ps2k_clk);             /* Wait for end of ACK time */
    pinMode(ps2k_clk, OUTPUT);
    digitalWrite(ps2k_clk, LOW);      /*   stop additional transmitting */

    // To make sure the keyboard sees the clock low, hold it for 200
    // microseconds.  That ensures any transfer started just before
    // this point is aborted rather than continuing if another poll
    // happens immediately after exit.
    delayMicroseconds (200);
}

// LK201 command buffer
uint8_t cmd[4];
int cmdcnt;

void send (int k)
{
  Serial.write (k);
}

void panic (char c, const int8_t * code)
{
    send (c);
    send_code (code);
    send (181);
}

void key (int lk, bool down)
{
    const int div = divs[lk - DIVBASE];

    if (down || modes[div] == U)
    {
        send (lk);
    }
    if (down && lk != 174 && (lk != 175 || ctrlClick))
    {
        doClick ();
    }
}

#define BREAK     0x01
#define MODIFIER  0x02
#define MODIFIER2  0x04

const uint8_t ps2_xlat[] =
{
    0,
    103,        // F9
    0,
    90,         // F5
    88,         // F3
    86,         // F1
    87,         // F2
    114,        // F12
    0,
    104,        // F10
    102,        // F8
    100,        // F6
    89,         // F4
    190,        // Tab
    191,        // `
    0,
    0,
    177,        // Left Alt (Compose)
    174,        // Left Shift
    0,
    175,        // Left Ctrl
    193,        // q
    192,        // 1
    0,
    0,
    0,
    195,        // z
    199,        // s
    194,        // a
    198,        // w
    197,        // 2
    0,
    0,
    206,        // c
    200,        // x
    205,        // d
    204,        // e
    208,        // 4
    203,        // 3
    0,
    0,
    212,        // Spacebar
    211,        // v
    210,        // f
    215,        // t
    209,        // r
    214,        // 5
    0,
    0,
    222,        // n
    217,        // b
    221,        // h
    216,        // g
    220,        // y
    219,        // 6
    0,
    0,
    0,
    227,        // m
    226,        // j
    225,        // u
    224,        // 7
    229,        // 8
    0,
    0,
    232,        // ,
    231,        // k
    230,        // i
    235,        // o
    239,        // 0
    234,        // 9
    0,
    0,
    237,        // .
    243,        // /
    236,        // l
    242,        // ;
    240,        // p
    249,        // -
    0,
    0,
    0,
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
    176,        // Caps Lock
    174,        // Right Shift
    189,        // Enter
    246,        // ]
    0,
    247,        // backslash
    0,
    0,
    0,
    0,
    0,
    0,
    0,
    0,
    188,        // Backspace
    0,
    0,
    150,        // Keypad 1 / End
    0,
    153,        // Keypad 4 / Left
    157,        // Keypad 7 / Home
    0,
    0,
    0,
    146,        // Keypad 0 / Ins
    148,        // Keypad . / Del
    151,        // Keypad 2 / Down
    154,        // Keypad 5
    155,        // Keypad 6 / Right
    158,        // Keypad 8 / Up
    113,        // Esc
    161,        // Num Lock (PF1)
    113,        // F11
    156,        // Keypad + (num comma)
    152,        // Keypad 3 / PgDn
    160,        // Keypad -
    163,        // Keypad * (PF3)
    159,        // Keypad 9 / PgUp
    124,        // Scroll Lock (Help)
    0,
    0,
    0,
    0,
    101,        // F7
};

// Key state is tracked by a double-linked list which gives keys
// currently down in time order.  There is a tail pointer (lastkey)
// but no head pointer, we have no need for that.  Each pointer is a
// key code, or 0 for first/last.  Keys currently up have next and
// prev both set to zero.  To tell the difference between key up and
// only this key down, look in lastkey; if an entry has 0 pointers but
// lastkey points to it, that key is down; otherwise it is up.
struct KeyState 
{
    uint8_t next;
    uint8_t prev;
};

KeyState vt220_keystate[256 - DIVBASE];
uint8_t lastkey;

// This function is invoked on each key stroke.  It resets autorepeat
// to act on the most recent key that has auto-repeat mode set, if
// any.
void update_ar (bool down)
{
    int lk = lastkey;
    int div;
    
    while (lk)
    {
        // Look for autorepeat key
        div = divs[lk - DIVBASE];
        if (modes[div] == A)
        {
            // We found the newest key that autorepeats
            break;
        }
        lk = vt220_keystate[lk - DIVBASE].prev;
    }
    if (lk == 0)
    {
        // Nothing autorepeats right now
        arTime = 0;
    }
    else
    {
        arBuf = &arbufs[ar[div]];
        arTime = millis () + arBuf->timeout;
        if (down && lk == lastkey)
        {
            // Key down and that key is the one autorepeating, so it
            // was just sent; we'll want metronome next.
            nextArKey = 180;
        }
        else
        {
            // Key up, or the autorepeating key isn't the one that was
            // just pressed, so send the autorepeating key next.
            nextArKey = lk;
        }
    }
}

// Convert PS2 scan code to LK201 key number.  Taken from ps2.c by
// Peter Bosch (peterbjornx).
int ps2_dataproc (unsigned int s)
{
    static uint8_t mods = 0;
    int c;

    s &= 0xff;
    //send (s);
    
    if (s == 0xF0) {
        mods |= BREAK;
        return 0;
    } else if (s == 0xE0) {
        mods |= MODIFIER;
        return 0;
    } else if (s == 0xE1) {
        mods |= MODIFIER2;
        return 0;
    }
    
    c = 0;
    if (mods & MODIFIER)
    {
        // Note: modifier E0 12 is prefixed onto Print Screen (always)
        // and onto a bunch of other keys like Windows and Right Ctrl
        // if NumLock is in effect (if that key has been pressed an
        // odd number of times).  So that code is ignored.
        switch (s)
        {
        case 0x11: c = 128; break;  // Right Alt (F17)
        case 0x14: c = 131; break;  // Right control (F20)
        case 0x1f: c = 201; break;  // Left Windows (< >)
        case 0x27: c = 129; break;  // Right Windows (F18)
        case 0x2f: c = 130; break;  // Applic (F19)
        case 0x4a: c = 162; break;  // Keypad / (PF2)
        case 0x5a: c = 149; break;  // Keypad Enter
        case 0x69: c = 142; break;  // End (Prev Screen)
        case 0x6b: c = 167; break;  // Left
        case 0x6c: c = 139; break;  // Home (Insert Here)
        case 0x70: c = 138; break;  // Insert (Find)
        case 0x71: c = 141; break;  // Delete (Select)
        case 0x72: c = 169; break;  // Down
        case 0x74: c = 168; break;  // Right
        case 0x75: c = 170; break;  // Up
        case 0x7a: c = 143; break;  // PgDn (Next Screen)
        case 0x7c: c = 116; break;  // PrtScr (F14)
        case 0x7d: c = 140; break;  // PgUp (Remove)
        case 0x7e: c = 125; break;  // Pause (Do) when Ctrl is active
        default:  break;
        }
    }
    else if (mods & MODIFIER2)
    {
        switch (s)
        {
            // The Pause key is a truly crazy case. It sends its "key
            // up" sequence immediately after the "down" sequence.
            // Second, it sends a sequence of two codes after the e1
            // modifier (but the modifier is only sent once).
            // Finally, if Control is down, it sends a completely
            // different sequence (e0 e7).  To handle the case of the
            // two-code sequence, when we see the first of the two we
            // ignore that but leave the modifiers set, so the second
            // code is also handled in this section of the code.
        case 0x14: return 0;        // Pause, first code
        case 0x77: c = 125; break;  // Pause (Do)
        default: break;
        }
    } else if (s < sizeof (ps2_xlat))
    {
        c = ps2_xlat[s];
    }

    if ((mods & BREAK) && (c != 0))
    {
        c |= 0x400;
    }
    mods = 0;
    
    return c;
}

void kserror (void)
{
    // Clear the key state data and send "all up"
    memset (vt220_keystate, 0, sizeof (vt220_keystate));
    lastkey = 0;
    arTime = 0;
    send (179);
    //send_code (errB);
}
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
void loop()
{
    // Check for input from host
    serialEvent();

    // Check for keyboard data
    kbpoll ();

    // Check for autorepeat to be done
    if (arTime && millis () >= arTime)
    {
        // Yes, and it just expired
        send (nextArKey);
        nextArKey = 180;        // Next time send metronome code
        doClick ();
        arTime = millis () + arBuf->interval;
    }
}

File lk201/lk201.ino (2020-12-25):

/*
 LK-201 emulator

 Interfaces between a DEC terminal or workstation that expects an
 LK201-AA keyboard and a standard PC type USB keyboard.

 Copyright (c) 2020, Paul Koning

 Please read file LICENSE for the license that applies to this project.
*/

#define DOIDENT 1   // Set to 0 to suppress power up ident

/*
 Parts of this code were taken from various sample files:

 KeyboardController tutorial
 created 8 Oct 2012
 by Cristian Maglie

 http://arduino.cc/en/Tutorial/KeyboardController
 This sample code is part of the public domain.

 3-color LED example from
 https://hackaday.io/project/9017-skywalker-lightsaber/log/72354-adafruit-trinket-m0-controlling-the-onboard-dotstar-led-via-arduino-ide

 ZeroTimer library example from
 https://github.com/adafruit/Adafruit_ZeroTimer/tree/master/examples/timer_callback
 */

#include <Arduino.h>
#include "Adafruit_ZeroTimer.h"

// Require keyboard control library
#include <KeyboardController.h>

#include <Adafruit_DotStar.h>
#include <SPI.h>

#define NUMPIXELS 1 // Number of LEDs in strip

// Here's how to control the LEDs from any two pins:
#define DATAPIN   7
#define CLOCKPIN   8

Adafruit_DotStar strip = Adafruit_DotStar(
  NUMPIXELS, DATAPIN, CLOCKPIN, DOTSTAR_BGR);

// PC 105-key keyboard (USB HID Boot mode codes) to LK201 mapping.
//
// Entries in the main lookup table are keyed by the scan code.  The
// value is the LK201 keycode.  Entries in the "divs" table are keyed
// by LK201 keycode, and give the "keyboard division" number which
// selects the mode (up/down, autorepeat, down only) and, if
// applicable, autorepeat parameter buffer.
//
// For the most part these mappings are obvious.  The 6 editing keys
// (above the cursor keys) are mapped according to their location, not
// their labels, so "home" is coded as LK201 "insert here" (rather than
// using the "insert" key for this code).
//
// Similarly, num lock, scroll lock and pause become F14, F15 (Help)
// and F16 (Do).  And the numeric keypad mappings are by layout.  Note
// that there is no PF4 because the PC keypad has one key less than the
// LK201, so the - key is used for - (Cut) instead of PF4 as its
// placement might suggest.
//
// The left Windows key is the < > key.
//
// For convenience, Esc is mapped to F11 which is its conventional
// interpretation.  Both shifts are shift, but the right
// Alt/Win/App/Ctrl keys are F17 to F20 instead.

const uint8_t divs[] =
{
  10, 10, 10, 10, 10, 0, 0, 0, 0, 0, 0, 0, 0, 0,
  11, 11, 11, 11, 11, 0, 0, 0, 0, 0, 0, 0, 0,
  12, 12, 12, 12, 0, 0, 0, 0, 0, 0, 0, 13, 13, 0, 0,
  14, 14, 14, 14, 0, 0, 0, 0, 0, 0, 9, 9, 9, 9, 9, 9,
  0, 0, 2, 0, 2, 2, 2, 2, 2, 2, 2, 2, 2, 2, 2, 2, 2, 2, 2, 2,
  0, 0, 0, 7, 7, 8, 8, 0, 0, 0, 6, 6, 5, 5, 0, 0, 0, 0,
  0, 0, 0, 0, 0, 0, 3, 4, 4, 1, 1, 1, 1, 1, 0, 1, 1, 1, 1, 1,
  0, 1, 1, 1, 1, 0, 1, 1, 1, 1, 1, 0, 1, 1, 1, 1, 0,
  1, 1, 1, 1, 0, 1, 1, 1, 1, 0, 1, 1, 1, 1, 0, 1, 1, 1, 1, 0,
  1, 1, 0, 1, 1, 0, 1, 1, 1, 0, 1, 1, 1
};
// First LK201 code in divs is 86
#define DIVBASE 86

// Main lookup table, indexed by report scan code
const uint8_t usb_lk201[] =
{
  0,               // No keys
  0,               // Rollover overflow
  0,               // error
  0,               // reserved
  194,             // A
  217,             // B
  206,             // C
  205,             // D
  204,             // E
  210,             // F
  216,             // G
  221,             // H
  230,             // I
  226,             // J
  231,             // K
  236,             // L
  227,             // M
  222,             // N
  235,             // O
  240,             // P
  193,             // Q
  209,             // R
  199,             // S
  215,             // T
  225,             // U
  211,             // V
  198,             // W
  200,             // X
  220,             // Y
  195,             // Z
  192,             // 1
  197,             // 2
  203,             // 3
  208,             // 4
  214,             // 5
  219,             // 6
  224,             // 7
  229,             // 8
  234,             // 9
  239,             // 0
  189,             // Enter
  113,             // Esc (F11)
  188,             // Backspace
  190,             // Tab
  212,             // Space
  249,             // - / _
  245,             // = / +
  250,             // [ / {
  246,             // ] / }
  247,             // \ / |
  0,               // unused code
  242,             // ; / :
  251,             // ' / "
  191,             // ` / ~
  232,             // , / <
  237,             // . / >
  243,             // / / ?
  176,             // Caps Lock
  86,              // F1
  87,              // F2
  88,              // F3
  89,              // F4
  90,              // F5
  100,             // F6
  101,             // F7
  102,             // F8
  103,             // F9
  104,             // F10
  113,             // F11
  114,             // F12
  116,             // PrtScr (F14)
  124,             // Scroll Lock (Help)
  125,             // Pause (Do)
  138,             // Insert (Find)
  139,             // Home (Insert here)
  140,             // PgUp (Remove)
  141,             // Delete (Select)
  142,             // End (Prev Screen)
  143,             // PgDn (Next Screen)
  168,             // Right
  167,             // Left
  169,             // Down
  170,             // Up
  161,             // Num Lock (PF1)
  162,             // KP / (PF2)
  163,             // KP * (PF3)
  160,             // KP -
  156,             // KP + (num comma)
  149,             // KP Enter
  150,             // KP 1 / End
  151,             // KP 2 / Down
  152,             // KP 3 / PgDn
  153,             // KP 4 / Left
  154,             // KP 5
  155,             // KP 6 / Right
  157,             // KP 7 / Home
  158,             // KP 8 / Up
  159,             // KP 9 / PgUp
  146,             // KP 0 / Ins
  148,             // KP . / Del
  0,               // unused code
  130              // Applic (F19)
};

#define MAXSCAN sizeof (usb_lk201)

// Modifier lookup table, indexed by bit number
const uint8_t usbmod_lk201[] =
{
  175,             // Left control
  174,             // Shift
  177,             // Left Alt (Compose)
  201,             // Left Windows  (< >)
  131,             // Right control (F20)
  0,               // Unused (right shift)
  128,             // Right Alt (F17)
  129              // Right Windows (F18)
};

// Modifier bit values
#define LCTRL  0x01
#define LSHIFT 0x02
#define LALT   0x04
#define LWIN   0x08
#define RCTRL  0x10
#define RSHIFT 0x20
#define RALT   0x40
#define RWIN   0x80

// Modes
#define D 0         // Down only
#define A 1         // Autorepeat
#define U 3         // Up/down
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

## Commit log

2020-06-20 Initial delivery.
    [lk201.kicad_pcb, lk201.sch]
2020-08-19 Add pointer to Digikey saved BOM.
2020-12-25 Fix wrong code for F9. Binary (lk201.uf2) updated to match.
    [lk201.ino]
2021-03-07 Initial commit of PS-2 version of keybaord emulator.
    [MDJ-00x.step, lk201.kicad_pcb, lk201.sch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]
2021-04-03 1. Update board date. This is board rev C 2. Bugfixes in scan software, fix a race condition between timing out keyboard data start and the arrival of the start bit. This requires holding clock low l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
    [lk201ps2.kicad_pcb]
2021-04-17 Remove line missed in previous cleanup.
    [lk201ps2.ino]
2021-04-17 Update board doc to point to OSHPark shared design file for PS2 board.
2021-05-11 Add public BOM link for PS2 based LK201 emulator.
2021-05-26 red diode clarification
